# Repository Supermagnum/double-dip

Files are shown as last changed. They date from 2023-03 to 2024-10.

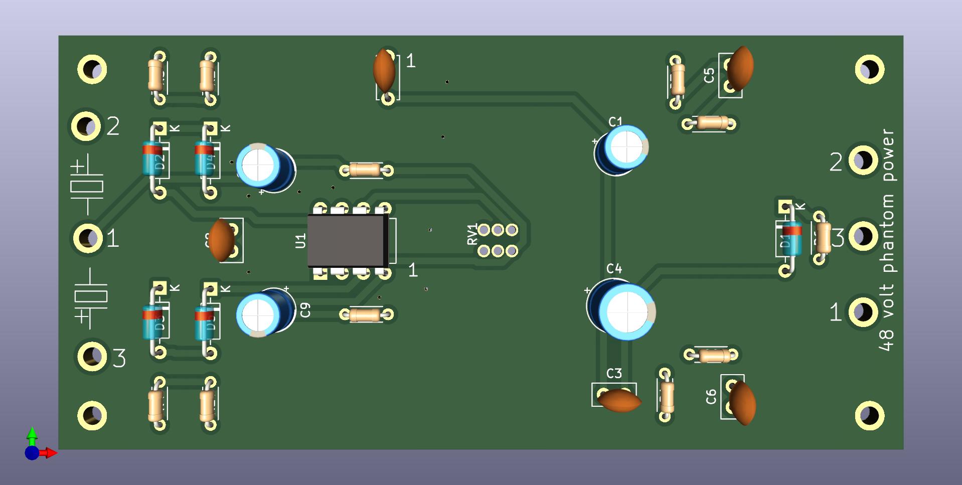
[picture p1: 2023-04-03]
front.jpg

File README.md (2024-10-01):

# double-dip
A small PCB that uses a TL082BCP chip with two op amps to amplify a signal from a contact microphone.

SMD adapter with LT6234 :
https://aisler.net/p/IXOHRKHO
https://github.com/Supermagnum/smd-adapter
It has lower self noise.

It has balanced output,input and runs on +48 phantom power. Shielded cable must be used for connection to the piezo crystals. Please use 0,5 W metal film resistors with 1% tolerance or better and audio quality capacitors.
C0G (NP0) or X7R capacitors is very good.

It is important that the circuit board is mounted inside a metal box, and Ø2mm conducting metal standoffs are used. The corner pads of the PCB board is reserved for that. Of course the PCB board and components must not come in contact with any metal surface expect the standoffs.

The circuit may benefit from a Zobel network, that is a 680 pF capacitor and a 150 ohms resistor in series between pin 2 and 3 on the output or the input connector. It should avoid high frequency oscillation in a long cable.

Why: The problem with piezo guitar pickups and piezoelectric crystals is that they are not well matched to typical audio inputs. By their nature they can generate a lot of signal, but they cannot drive a 50 kilohm typical line input. The pickup needs to work into a much higher impedance, typically 1 megohm or so.

So what to people do? They go and plug a piezoelectric disks output directly into the line input of their recorder, typical impedance 50k, or the plug-in-power mic input of their recorder, typical impedance about 7k, and they start to bitch and moan that this damn thing sounds tinny. Which is does ! But they don't understand why!

The reason why these devices often sound tinny is because the piezo sensor presents its signal through a series capacitance which is small, typically 15nF or less. When wired to a normal 50 kilohm line input this forms a high-pass filter, which eliminates the bass.

This circuit board solves that, and amplifies the signal. How many dB it amplifies is dependent on the resistance on the resistors used.The data for that is on the schematic diagram.

It's fairly easy and straight forward to solder the components to the circuit board, a nice pointy soldering iron, solder, a magnifying glass, and a ohm or multimeter is all that is needed. Of course one needs a suitable metal box, and the circuit boards components must not come in contact with the metal box. That will cause short circuit, so it's best mounted on stand offs. Also, use the magnifying glass to check that no one of the soldering pads has been bridged.

It can be used for a reverb plate, listening to the insides of a engine,recording the sound of vibrating things. You will need two piezoelectric disks for that, mounted in a metal box. Non electric conductive super glue is useable for that. Just glue them to a flat surface. The piezoelectric disks should be electrically insulated from the metal box.

Mechanics may even use it to discover trouble with bearings or other mechanisms not easily opened, but it will need a dedicated +48 volts phantom power supply with headphone jack for that specific usage.

Of course one can use a recorder like a tascam dr40x, as long as it can supply +48 volt phantom power, and has a headphone jack for monitoring.

A good set of headphones or ear protection with built in speakers will keep out unwanted sounds or noise.

Should also work nice with hydrophones. PZT-5H tubes is best for that. You want more gain, 35 or 40 dB for that. In case of a hydrophone it's possible to have the hydrophone attached with a long cable and the amplifier/buffer circuit close to the piezoelectric elements. It's of course extremely important that the circuit board and connections are absolutely waterproof. A epoxy filled container or inside the hydrophone bulb is OK. Commercial ones uses kerosene oil, so olive oil or sunflower oil is a great alternative as it will not pollute the environment if any leaks occurs.

Some interesting ideas can be found in: https://github.com/Supermagnum/piezo-balanced/blob/main/Barlow-et-al-2008-HydrophoneConstruction_TM-417.pdf 
Note: Ecopoxy Flowcast does not need any vacuum, just a mold and a way to hold the piezoelectric tubes centered. It's also safer to work with. Of course two piezoelectric disks inside something waterproof that can handle the water pressure is also useable. 

I used a simple metal box with thin walls that used to contain candy and filled it with food grade silicone.

The XLR 3 pin plug has a solder lug for the shield for a reason. Connect the shield and the drain wire to that spesific lug.
Those are wired up like this: https://github.com/Supermagnum/piezo-balanced/blob/main/XLR%2BConnector%2BPinout%2BDiagram%2BRear%2BPin%2B2%2BHot%2Bv2%2Bgreen__01.jpg

It is my opinion that a shielded cable with 3 conductors inside is the best. Suggested cable: Digi-Key Part Number: 30-00910-5-ND

Piezoelectric disk, red wire for positive polarity. Black for negative: https://github.com/Supermagnum/double-gain/blob/main/Piezo-element-6.jpg

Based on: http://www.richardmudhar.com/blog/piezo-contact-microphone-hi-z-amplifier-low-noise-version/

Some methods of mounting a piezoelectric disk can be found here: https://locusonus.org/wiki/index.php?page=Hydrophone.en

Top of PCB: https://github.com/Supermagnum/double-dip/blob/main/front.jpg

Top of pcb without components:https://github.com/Supermagnum/double-dip/blob/main/bare-front.jpg

Bottom of PCB: https://github.com/Supermagnum/double-dip/blob/main/back.jpg

Dimentions:
https://github.com/Supermagnum/double-dip/blob/main/dimentions.png

Schematic diagram: https://github.com/Supermagnum/double-dip/blob/main/tht-dip.pdf

Aisler: https://aisler.net/p/HVXYPXGN

Made with: http://www.kicad.org/

KiCad uses an integrated environment for all of the stages of the design process: Schematic capture, PCB layout, Gerber file generation/visualization, and library editing.

KiCad is a cross-platform program, and free!

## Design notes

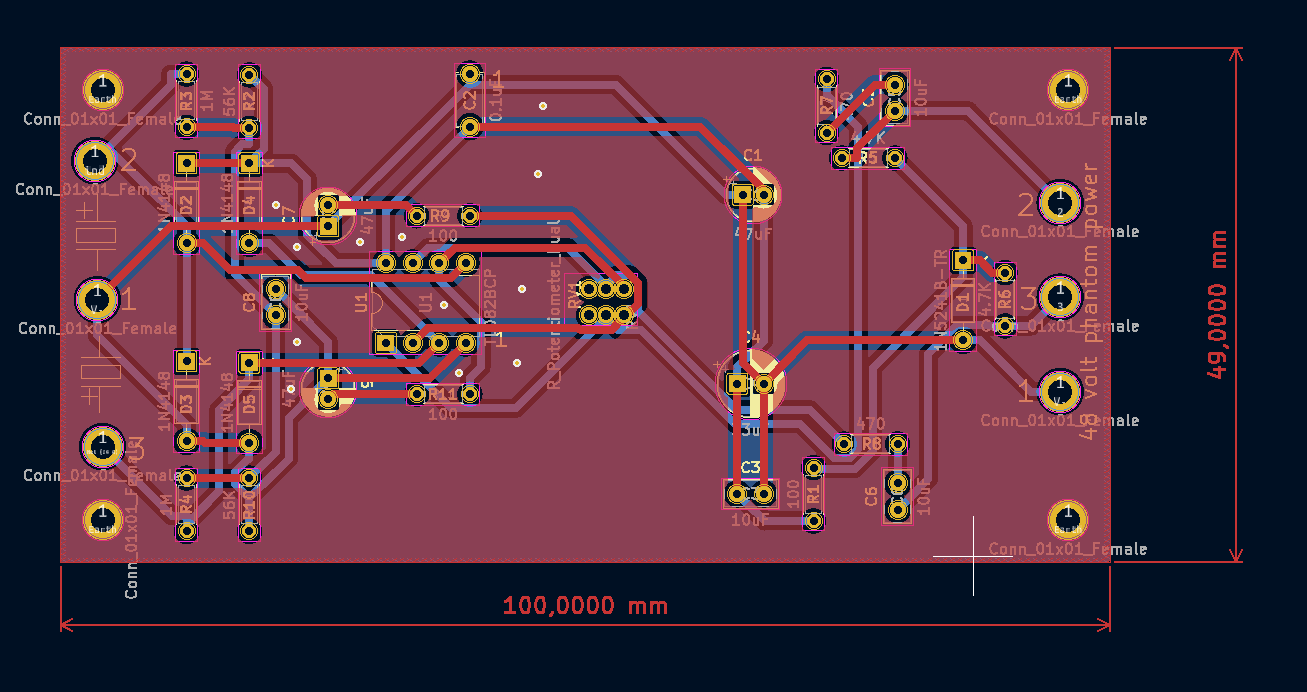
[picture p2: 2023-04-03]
dimentions.png

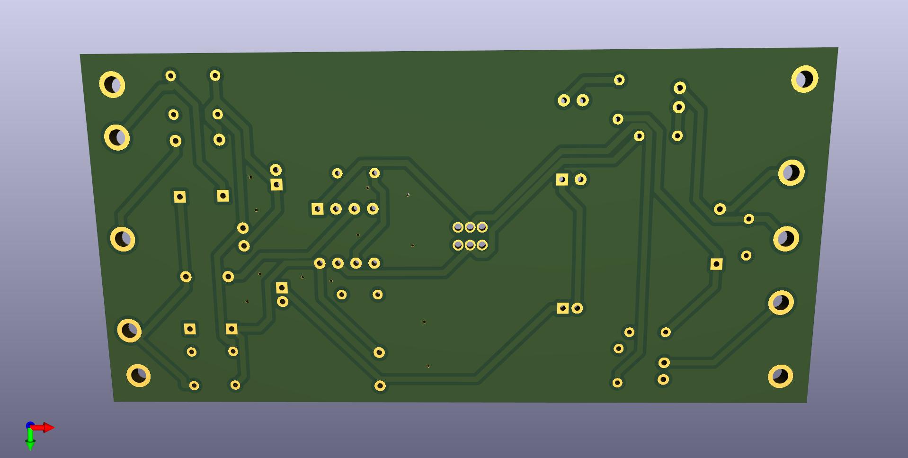
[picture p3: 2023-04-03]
back.jpg

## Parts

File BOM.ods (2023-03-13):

Source: | /mnt/b955457f-512b-4f44-a0f7-8e5f2b78aba2/double-dip-main/tht-dip.sch
Date: | ma. 13. mars 2023 kl. 12.07 +0100
Tool: | Eeschema 7.0.0-da2b9df05c~171~ubuntu22.04.1
Generator: | /usr/share/kicad/plugins/bom_csv_grouped_by_value.py
Component Count: | 54
Collated Components:
Item | Qty | Reference(s) | Value | LibPart | Footprint | Datasheet | DNP | Sim.Device | Sim.Pins
1 | 1 | C1 | 0.1uF | Device:C | Capacitor_THT:C_Disc_D5.0mm_W2.5mm_P5.00mm | ~
2 | 4 | C2, C4, C5, C7 | 10uF | Device:C | Capacitor_THT:C_Disc_D5.0mm_W2.5mm_P2.50mm | ~
3 | 1 | C3 | 33uF | tht-dip-rescue:CP-Device | Capacitor_THT:CP_Radial_D6.3mm_P2.50mm
4 | 3 | C6, C8, C9 | 47uF | Device:C | Capacitor_THT:C_Disc_D5.0mm_W2.5mm_P2.50mm | ~
5 | 1 | D1 | 1N5241B-TR | Device:D_Zener | Diode_THT:D_DO-35_SOD27_P7.62mm_Horizontal | ~
6 | 4 | D2, D3, D4, D5 | 1N4148 | Device:D | Diode_THT:D_DO-35_SOD27_P7.62mm_Horizontal | ~ |  |  | D | 1=K 2=A
7 | 10 | J1, J2, J3, J4, J5, J6, J7, J8, J9, J10 | Conn_01x01_Female | tht-dip-rescue:Conn_01x01_Female-Connector | MountingHole:MountingHole_2.2mm_M2_ISO7380_Pad
8 | 3 | R1, R9, R11 | 100 | Device:R | Resistor_THT:R_Axial_DIN0204_L3.6mm_D1.6mm_P5.08mm_Horizontal | ~
9 | 2 | R2, R10 | 56K | Device:R | Resistor_THT:R_Axial_DIN0204_L3.6mm_D1.6mm_P5.08mm_Horizontal | ~
10 | 2 | R3, R4 | 1M | Device:R | Resistor_THT:R_Axial_DIN0204_L3.6mm_D1.6mm_P5.08mm_Horizontal | ~
11 | 2 | R5, R6 | 4.7K | Device:R | Resistor_THT:R_Axial_DIN0204_L3.6mm_D1.6mm_P5.08mm_Horizontal | ~
12 | 2 | R7, R8 | 470 | Device:R | Resistor_THT:R_Axial_DIN0204_L3.6mm_D1.6mm_P5.08mm_Horizontal | ~
13 | 2 | R12, R20 | 1K | Device:R | Resistor_THT:R_Axial_DIN0204_L3.6mm_D1.6mm_P5.08mm_Horizontal | ~
14 | 2 | R13, R21 | 3K | Device:R | Resistor_THT:R_Axial_DIN0204_L3.6mm_D1.6mm_P5.08mm_Horizontal | ~
15 | 2 | R14, R22 | 4K | Device:R | Resistor_THT:R_Axial_DIN0204_L3.6mm_D1.6mm_P5.08mm_Horizontal | ~
16 | 2 | R15, R23 | 5K | Device:R | Resistor_THT:R_Axial_DIN0204_L3.6mm_D1.6mm_P5.08mm_Horizontal | ~
17 | 2 | R16, R24 | 6K | Device:R | Resistor_THT:R_Axial_DIN0204_L3.6mm_D1.6mm_P5.08mm_Horizontal | ~
18 | 2 | R17, R25 | 7K | Device:R | Resistor_THT:R_Axial_DIN0204_L3.6mm_D1.6mm_P5.08mm_Horizontal | ~
19 | 2 | R18, R26 | 8K | Device:R | Resistor_THT:R_Axial_DIN0204_L3.6mm_D1.6mm_P5.08mm_Horizontal | ~
20 | 2 | R19, R27 | 700 | Device:R | Resistor_THT:R_Axial_DIN0204_L3.6mm_D1.6mm_P5.08mm_Horizontal | ~
21 | 2 | SW1, SW2 | JS0108AP4-S | Switch:SW_DIP_x08 | Package_DIP:DIP-16_W7.62mm | ~
22 | 1 | U1 | TL082BCP | Amplifier_Operational:TL082 | Package_DIP:DIP-8_W7.62mm | http://www.ti.com/lit/ds/symlink/tl081.pdf

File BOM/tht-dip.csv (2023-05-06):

Source: | /mnt/b955457f-512b-4f44-a0f7-8e5f2b78aba2/double-dip-main/tht-dip.kicad_sch
Date: | ma. 13. mars 2023 kl. 14.35 +0100
Tool: | Eeschema 7.0.0-da2b9df05c~171~ubuntu22.04.1
Generator: | /usr/share/kicad/plugins/bom_csv_grouped_by_value.py
Component Count: | 37
Collated Components:
Item | Qty | Reference(s) | Value | LibPart | Footprint | Datasheet | DNP | Sim.Device | Sim.Pins
1 | 3 | C1, C7, C9 | 47uF | Device:C | Capacitor_THT:CP_Radial_D5.0mm_P2.00mm | ~
2 | 1 | C2 | 0.1uF | Device:C | Capacitor_THT:C_Disc_D5.0mm_W2.5mm_P5.00mm | ~
3 | 4 | C3, C5, C6, C8 | 10uF | Device:C | Capacitor_THT:C_Disc_D5.0mm_W2.5mm_P2.50mm | ~
4 | 1 | C4 | 33uF | tht-dip-rescue:CP-Device | Capacitor_THT:CP_Radial_D6.3mm_P2.50mm
5 | 1 | D1 | 1N5241B-TR | Device:D_Zener | Diode_THT:D_DO-35_SOD27_P7.62mm_Horizontal | ~
6 | 4 | D2, D3, D4, D5 | 1N4148 | Device:D | Diode_THT:D_DO-35_SOD27_P7.62mm_Horizontal | ~ |  |  | D | 1=K 2=A
7 | 10 | J1, J2, J3, J4, J5, J6, J7, J8, J9, J10 | Conn_01x01_Female | tht-dip-rescue:Conn_01x01_Female-Connector | MountingHole:MountingHole_2.2mm_M2_ISO7380_Pad
8 | 3 | R1, R9, R11 | 100 | Device:R | Resistor_THT:R_Axial_DIN0204_L3.6mm_D1.6mm_P5.08mm_Horizontal | ~
9 | 2 | R2, R10 | 56K | Device:R | Resistor_THT:R_Axial_DIN0204_L3.6mm_D1.6mm_P5.08mm_Horizontal | ~
10 | 2 | R3, R4 | 1M | Device:R | Resistor_THT:R_Axial_DIN0204_L3.6mm_D1.6mm_P5.08mm_Horizontal | ~
11 | 2 | R5, R6 | 4.7K | Device:R | Resistor_THT:R_Axial_DIN0204_L3.6mm_D1.6mm_P5.08mm_Horizontal | ~
12 | 2 | R7, R8 | 470 | Device:R | Resistor_THT:R_Axial_DIN0204_L3.6mm_D1.6mm_P5.08mm_Horizontal | ~
13 | 1 | RV1 | 51ABD-B28-B15/B15L | Device:R_Potentiometer_Dual | potmeter:51ABD-B28-B15/B15L | ~
14 | 1 | U1 | TL082BCP | Amplifier_Operational:TL082 | Package_DIP:DIP-8_W7.62mm | http://www.ti.com/lit/ds/symlink/tl081.pdf

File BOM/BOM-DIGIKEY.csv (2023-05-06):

Index | Quantity | Part Number | Manufacturer Part Number | Description | Customer Reference | Available | Backorder | Unit Price | Extended Price USD
1 | 2 | BC4506CT-ND | MBB0207VD1004BC100 | RES 1M OHM 0.1% 0.4W AXIAL |  | 2 | 0 | 0.67000 | 1.34
2 | 2 | S56KCACT-ND | RNMF14FTC56K0 | RES 56K OHM 1% 1/4W AXIAL |  | 2 | 0 | 0.10000 | 0.20
3 | 2 | 13-MFR-25FTF52-4K7CT-ND | MFR-25FTF52-4K7 | RES 4.7K OHM 1% 1/4W AXIAL |  | 2 | 0 | 0.10000 | 0.20
4 | 1 | 51ABD-B28-B15/B15L | 51ABD-B28-B15/B15L | POT 10K OHM LINEAR |  | 1 | 0 | , | 5" | 2 | 399-ESK476M016AC3KACT-ND | ESK476M016AC3KA | CAP ALUM 47UF 20% 16V RADIAL | 2 | 0 | 0.23000 | 0.46
6 | 1 | 1N5241B-TRGICT-ND | 1N5241B-TR | DIODE ZENER 11V 500MW DO35 |  | 1 | 0 | 0.24000 | 0.24
7 | 4 | 1N4148FS-ND | 1N4148 | DIODE GEN PURP 100V 200MA DO35 |  | 4 | 0 | 0.10000 | 0.40
8 | 3 | 13-MFR-12FTF52-100RCT-ND | MFR-12FTF52-100R | RES 100 OHM 1% 1/6W AXIAL |  | 3 | 0 | 0.10000 | 0.30
9 | 2 | 13-MFR-25FTE52-470RCT-ND | MFR-25FTE52-470R | RES 470 OHM 1% 1/4W AXIAL |  | 2 | 0 | 0.10000 | 0.20
10 | 1 | BC1101CT-ND | K104K15X7RF5TH5 | CAP CER 0.1UF 50V X7R RADIAL |  | 1 | 0 | 0.23000 | 0.23
11 | 3 | 445-173297-1-ND | FG20X7R1H106KRT06 | CAP CER 10UF 50V X7R RADIAL |  | 3 | 0 | 1.27000 | 3.81
12 | 1 | 445-173432-1-ND | FG26X5R1E336MRT06 | CAP CER 33UF 25V X5R RADIAL |  | 1 | 0 | 0.94000 | 0.94
13 | 1 | 1528-2248-ND | 2230 | BOX ALUM BLACK 3.7"L X 3.27"W |  | 0 | 1 | 5.95000 | 5.95
14 | 4 | 668-1448-ND | AB1541B-LW100-R | BUZZER ELEMENT STD 4.1KHZ 15MM |  | 4 | 0 | 1.02000 | 4.08
15 | 16 | 2389-CF240-01-03-ND | CF240-01-03 | CABLE 3COND 26AWG GRAY SHLD FEET |  | 16 | 0 | 1.44000 | 23.04
16 | 2 | 1003-1235-ND | XLR312C | CONN PLUG MALE XLR 3P SOLDER |  | 2 | 0 | 14.04000 | 28.08
17 | 2 | 889-1797-ND | AC3FDZ | CONN PLUG FMALE XLR 3P SLDR CUP |  | 2 | 0 | 5.18000 | 10.36

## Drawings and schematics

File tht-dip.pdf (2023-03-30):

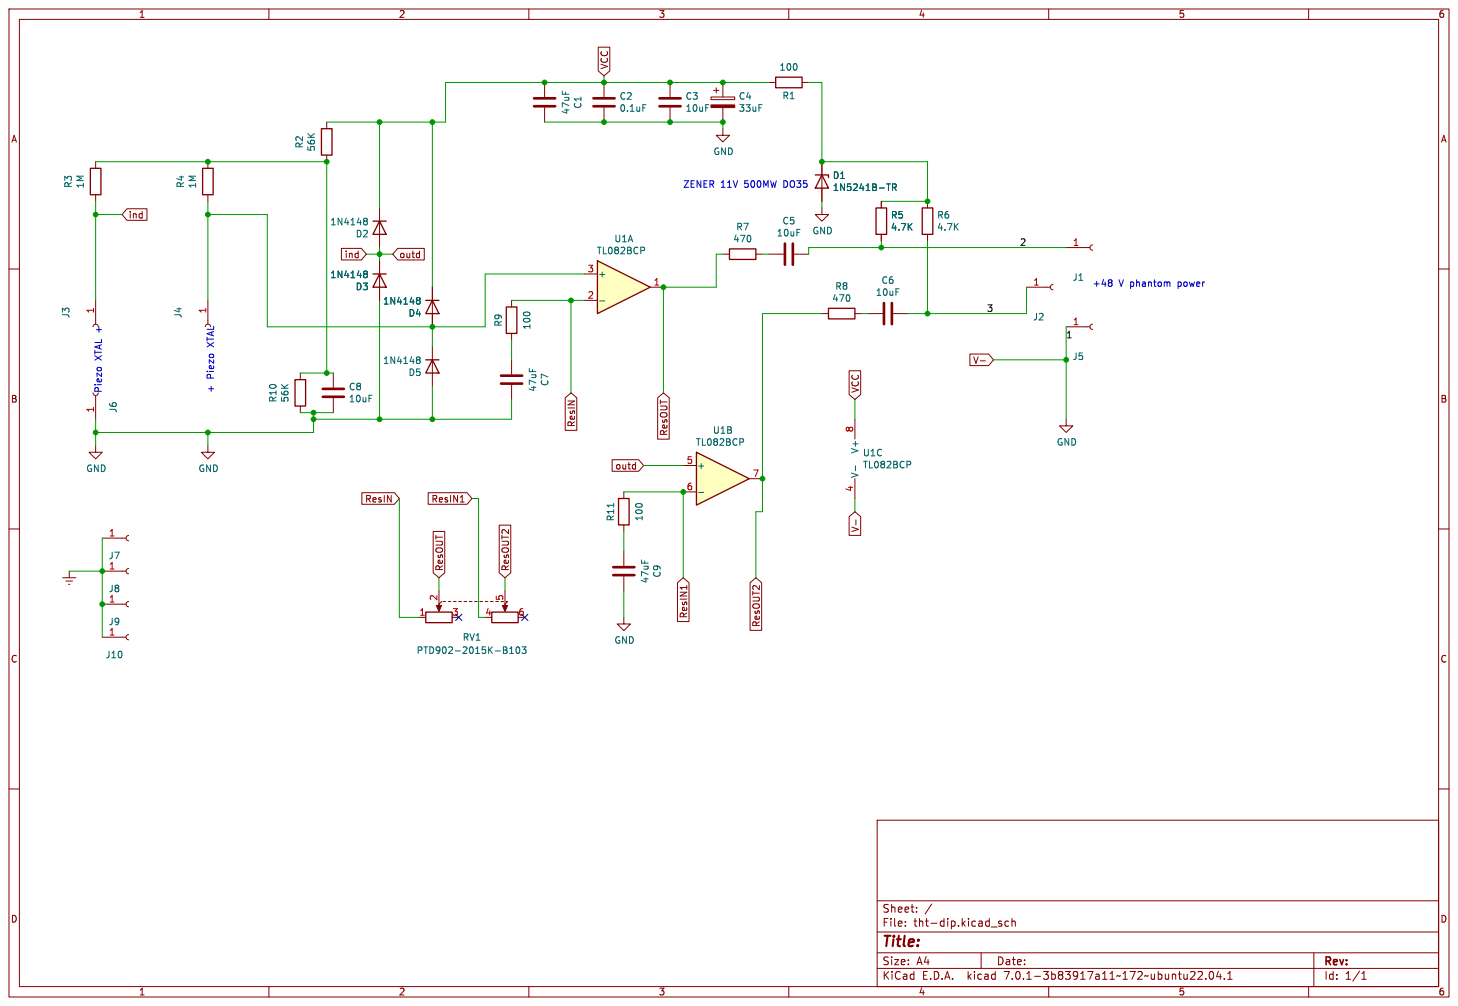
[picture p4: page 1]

3 ZENER 11V 500MW DO35 + Piezo XTAL Piezo XTAL +

Id: 1/1 Title: File: tht-dip.kicad_sch Sheet: /

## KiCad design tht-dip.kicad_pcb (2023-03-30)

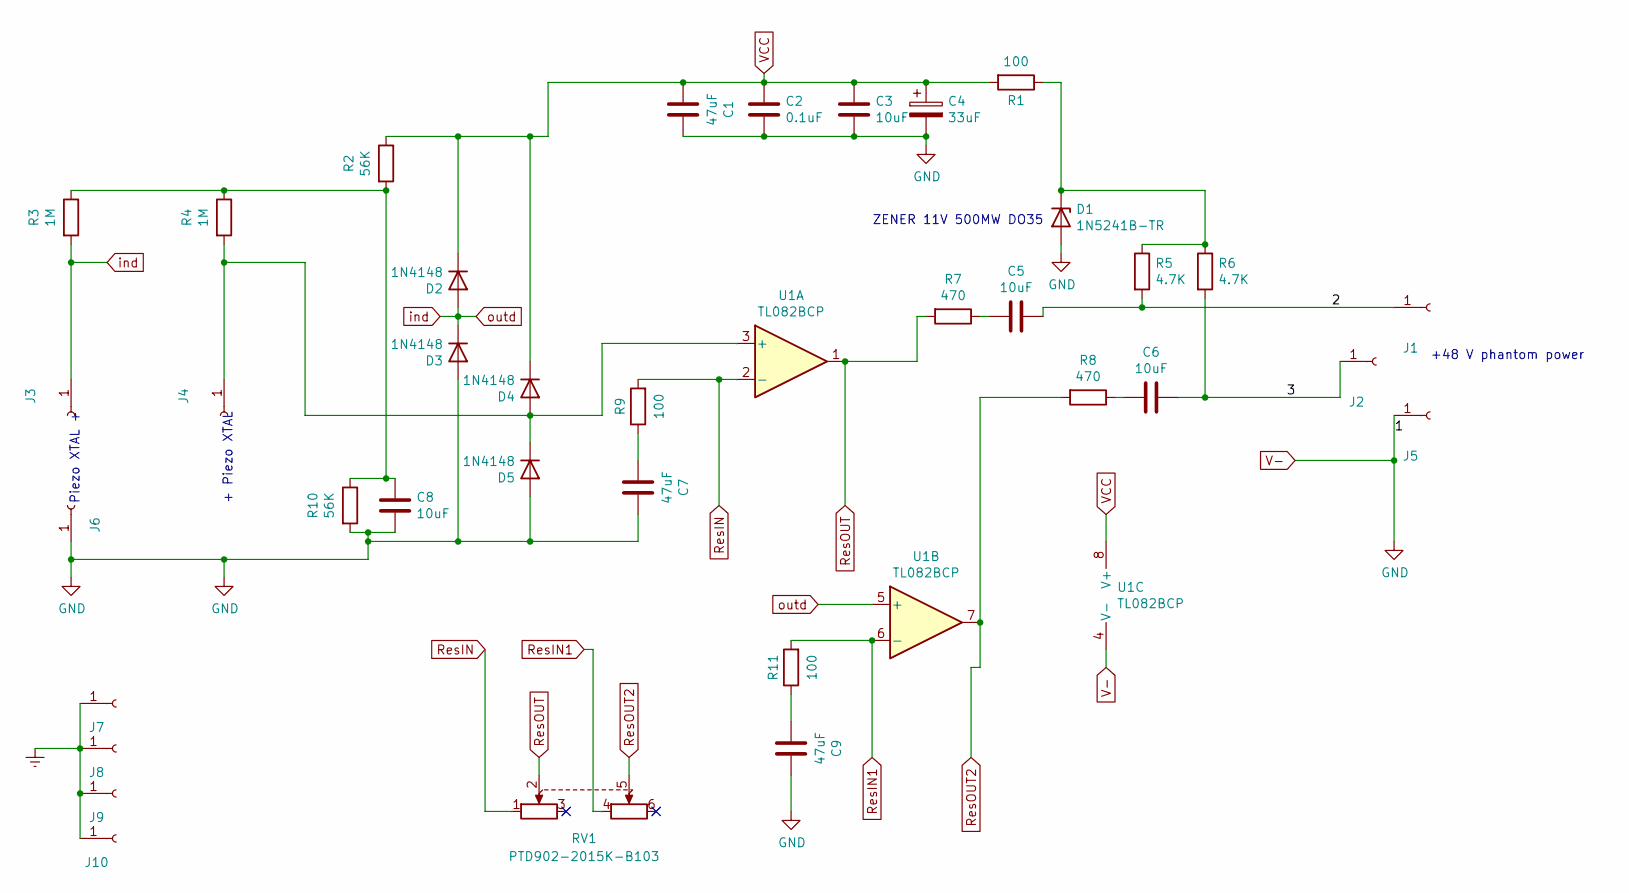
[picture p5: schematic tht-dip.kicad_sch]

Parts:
C1, C7, C9: 47uF; CP_Radial_D5.0mm_P2.00mm
C2: 0.1uF; C_Disc_D5.0mm_W2.5mm_P5.00mm
C3, C5, C6, C8: 10uF; C_Disc_D5.0mm_W2.5mm_P2.50mm
C4: 33uF; CP_Radial_D6.3mm_P2.50mm
D1: 1N5241B-TR; D_DO-35_SOD27_P7.62mm_Horizontal
D2, D3, D4, D5: 1N4148; D_DO-35_SOD27_P7.62mm_Horizontal
J1, J2, J3, J4, J5, J6, J7, J8, J9, J10: Conn_01x01_Female; MountingHole_2.2mm_M2_ISO7380_Pad
R1, R9, R11: 100; R_Axial_DIN0204_L3.6mm_D1.6mm_P5.08mm_Horizontal
R2, R10: 56K; R_Axial_DIN0204_L3.6mm_D1.6mm_P5.08mm_Horizontal
R3, R4: 1M; R_Axial_DIN0204_L3.6mm_D1.6mm_P5.08mm_Horizontal
R5, R6: 4.7K; R_Axial_DIN0204_L3.6mm_D1.6mm_P5.08mm_Horizontal
R7, R8: 470; R_Axial_DIN0204_L3.6mm_D1.6mm_P5.08mm_Horizontal
RV1: PTD902-2015K-B103
U1: TL082BCP; DIP-8_W7.62mm

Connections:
/2: C5.1, J1.1, R5.2
/3: C6.1, J2.1, R6.2
Earth: J7.1, J8.1, J9.1, J10.1
unnamed: C5.2, R7.1
unnamed: C6.2, R8.1
unnamed: C7.2, R9.1
unnamed: C8.1, R2.2, R3.1, R4.1, R10.1
unnamed: C9.2, R11.1
unnamed: D1.1 (K), R1.1, R5.1, R6.1
unnamed: D4.2 (A), D5.1 (K), J4.1, R4.2, U1.3 (+)
ResIN: R9.2, RV1.1, U1.2 (-)
ResIN1: R11.2, RV1.4, U1.6 (-)
ResOUT: R7.2, RV1.2, U1.1
ResOUT2: R8.2, RV1.5, U1.7
V-: C1.1, C2.2, C3.2, C4.2, C7.1, C8.2, C9.1, D1.2 (A), D3.2 (A), D5.2 (A), J5.1, J6.1, R10.2, U1.4 (V-)
VCC: C1.2, C2.1, C3.1, C4.1, D2.1 (K), D4.1 (K), R1.2, R2.1, U1.8 (V+)
ind: D2.2 (A), D3.1 (K), J3.1, R3.2, U1.5 (+)

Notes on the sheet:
ZENER 11V 500MW DO35
+ Piezo XTAL
Piezo XTAL +
+48 V phantom power

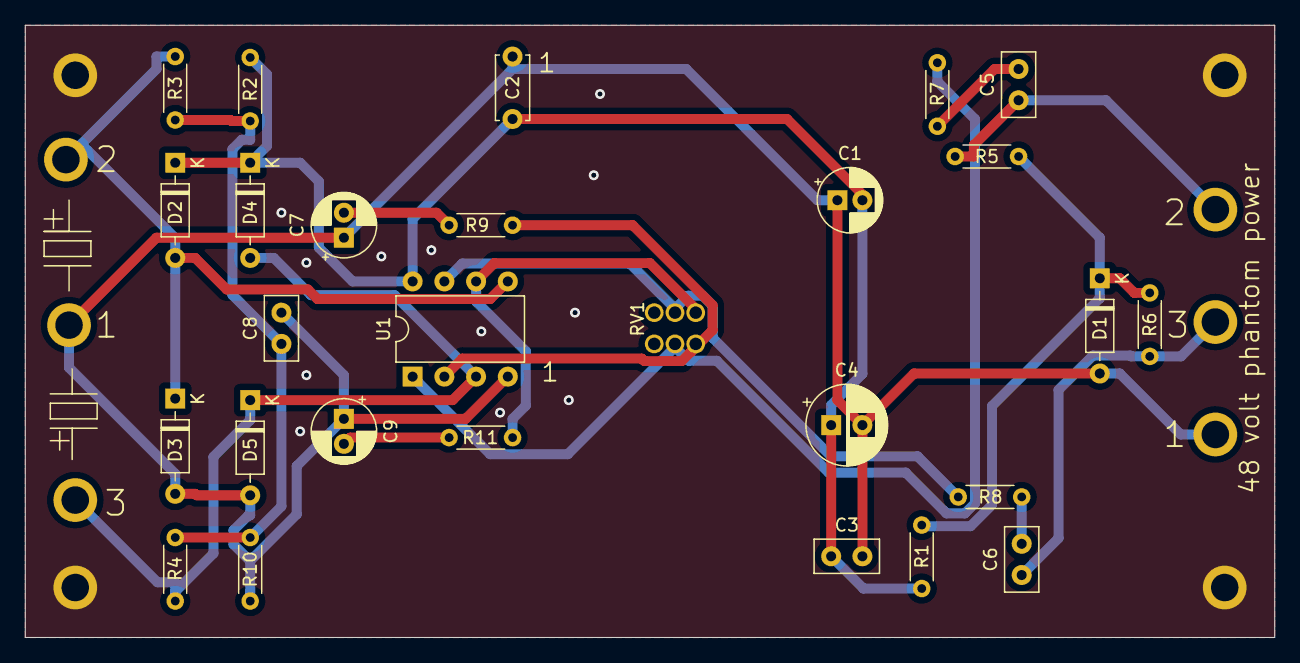
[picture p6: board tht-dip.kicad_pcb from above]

Board: 2 copper layers, 100.0 x 49.0 mm, 37 parts (0 on the bottom side), 17 nets.

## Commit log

2021-07-04 Add files via upload
    updated files.
    [tht-dip-B_Cu.gbr, tht-dip-B_Mask.gbr, tht-dip-B_Paste.gbr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]
2021-07-16 Add files via upload
    Updated, with the addition of a 700 ohm resistor.
    [tht-dip-B_Cu.gbr, tht-dip-B_Mask.gbr, tht-dip-B_Paste.gbr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]
2021-07-17 Add files via upload
    Changed to TL082BCP , less current use.
    [tht-dip-B_Adhes.gbr, tht-dip-B_CrtYd.gbr, tht-dip-B_Cu.gbr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]
